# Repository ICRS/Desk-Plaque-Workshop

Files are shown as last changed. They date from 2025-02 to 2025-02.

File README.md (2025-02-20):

# Desk Plaque Workshop

<br>

This is a workshop to make a desk plaque with your name on it. This plaque is lit by LEDs underneath the acrylic nameplate. It is powered by a USB C port and was originally made in the ICRS Robotics lab.

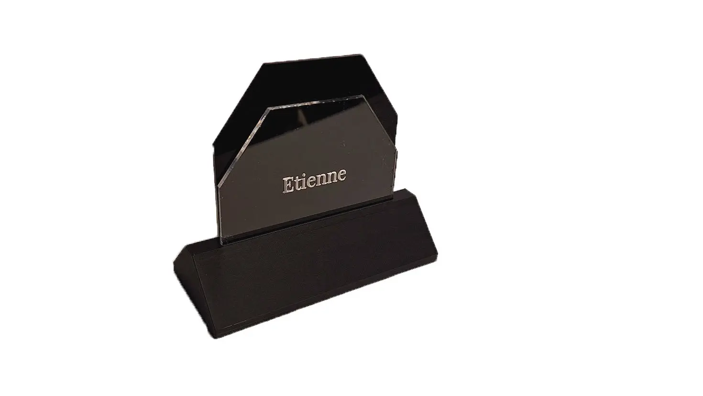
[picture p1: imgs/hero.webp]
hero


<br>
<br>
<br>

| 🔨 Tools | 🪵 Materials |
| ---  | --- |
| Laser Cutter (eg OMTech 60W) | 3mm Black Acrylic |
| 3D Printer (eg Bambu p1p) | 3mm Transparent Acrylic |
| Hot Glue Gun | 3mm Laser Rubber |
| Pliers | PLA Filament |
| Vector Editing Software (eg Inkscape)| USB C Port |
| | Fine Sand |
| | 120 LED/m Warm White LEDs |
| | USB C Cable |

## 📐 Making Parts

#### ⚡ Laser cutting:

1. Follow the instructions in `Name Plate.svg`
2. Remove the protective film from the acrylic
3. Cut out `Name Plate.svg` in the materials specified

#### 🖨️ 3D Printing:

Print all files in `3D files` folder

Use the following settings:

- 0.2mm Layer Height
- 2 Perimeters
- Supports enabled and 0.2mm from parts

Note that the infill percentage for this print doesn't matter.

## 🛠️ Assembly

#### `Electronics:`

1. Cut the LED strip to fit the hole in the base
2. Solder to USB C port

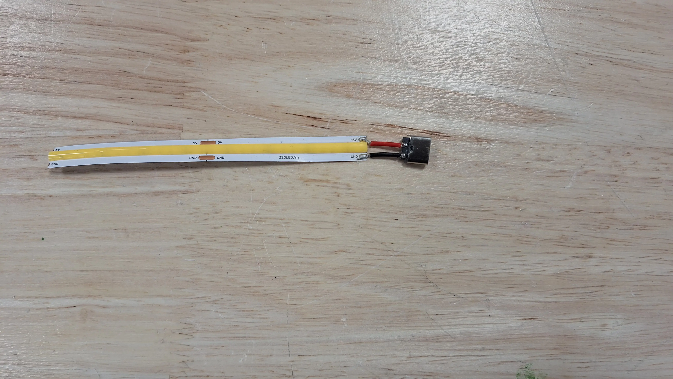
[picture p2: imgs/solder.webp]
LED Strip


#### `Base:`

1. Remove Support from the 3D printed parts
2. Fill the holes of the base with sand
3. Use hot glue to seal the sand holes and add the covers to the base to prevent sand from leaking

---

4. Add the LED strip to the base
5. Cover the LED strip with the 3D printed part and use it to hold the USB C port in place
6. Glue the rubber sheet to the bottom of the base to make it slide less and cover seams

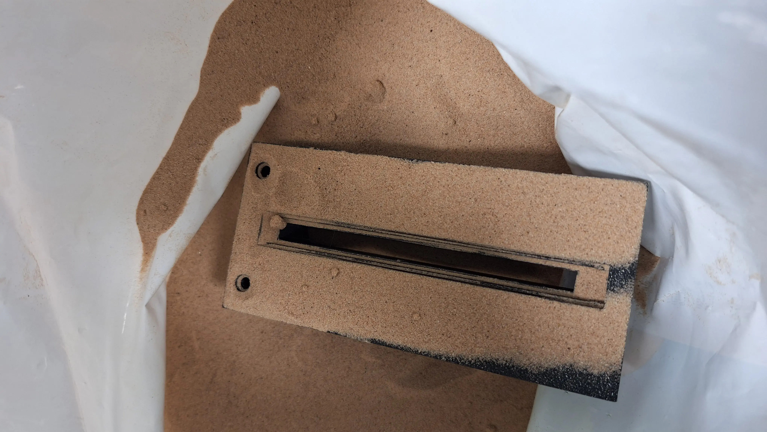
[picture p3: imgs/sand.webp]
sand

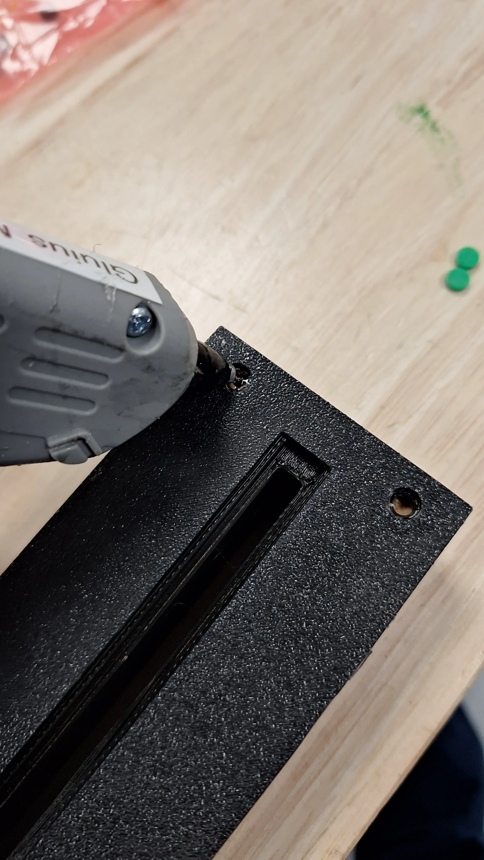
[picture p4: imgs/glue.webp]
glue

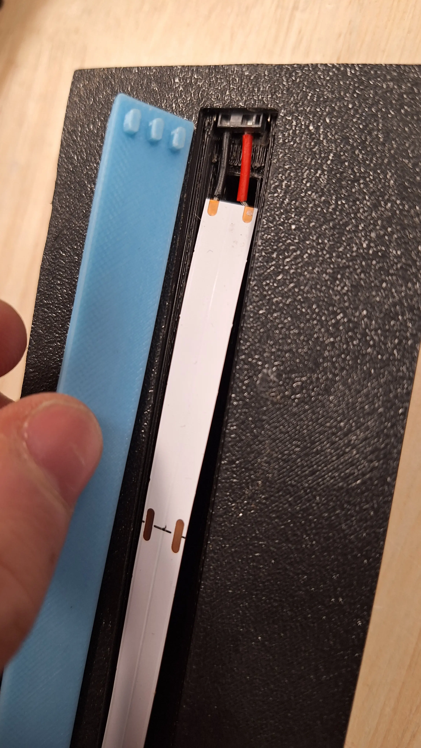
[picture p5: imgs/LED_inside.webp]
led placement


#### `Acrylic:`

1. Remove the protective film from the acrylic
2. Put the transparent acrylic in the slot of the base, with the text facing the inside for maximum contrast
3. Use mallet to gently push the acrlic plate into the slot
4. Then add the black acrylic and mallet it in
5. Plug the USB C port to a power source and enjoy!

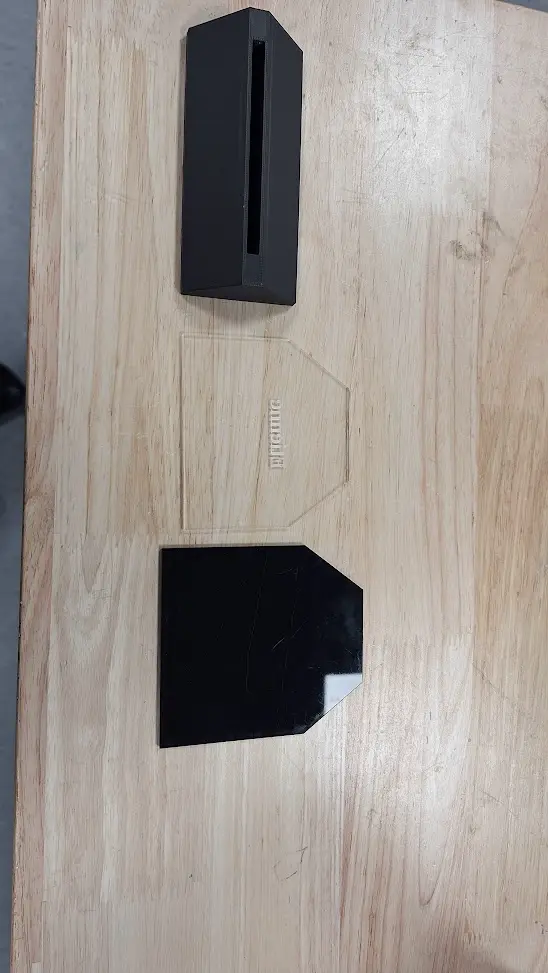
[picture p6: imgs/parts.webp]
parts

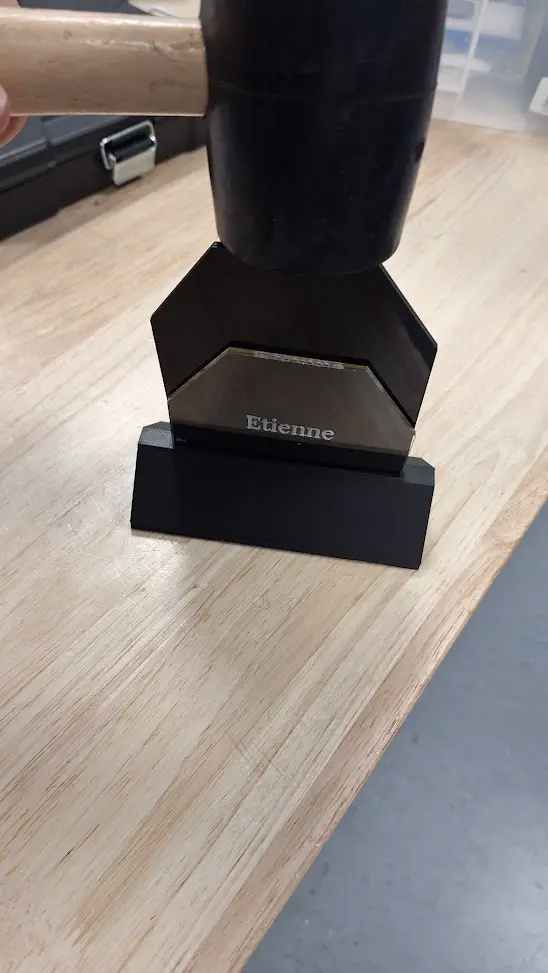
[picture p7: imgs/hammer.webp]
hammer in


### 📞 Contact

Course Designed for [Imperial College Robotics Society](https://linktr.ee/icrobotics)
By
- [Etienne Naude](https://etinaude.dev/contact/)
- [Anna Silver] (anna.silver22@imperial.ac.uk)
- Laura Shaw
- David Cai

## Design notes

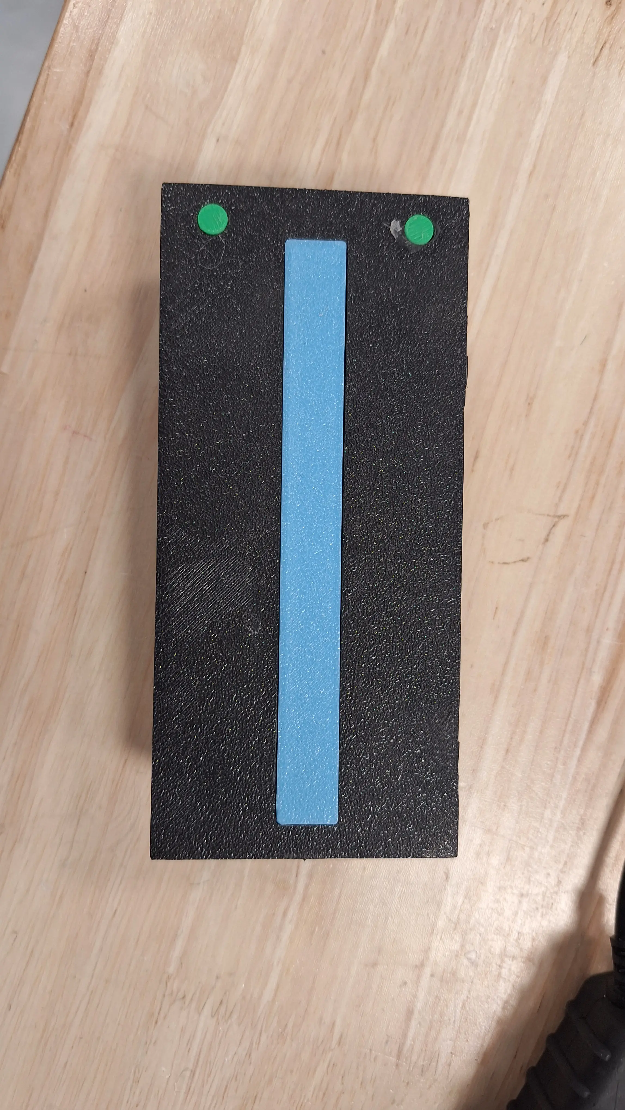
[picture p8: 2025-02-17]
imgs/bottom.webp

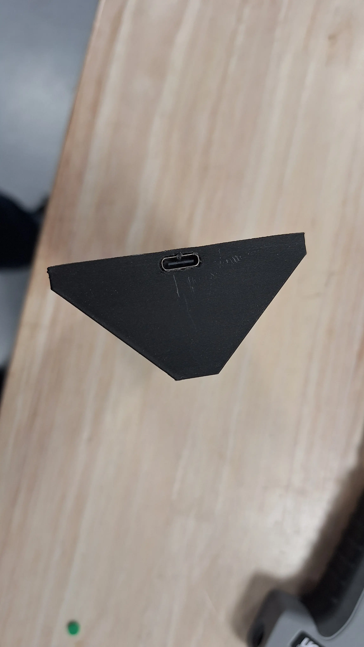
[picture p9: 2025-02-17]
imgs/usb.webp

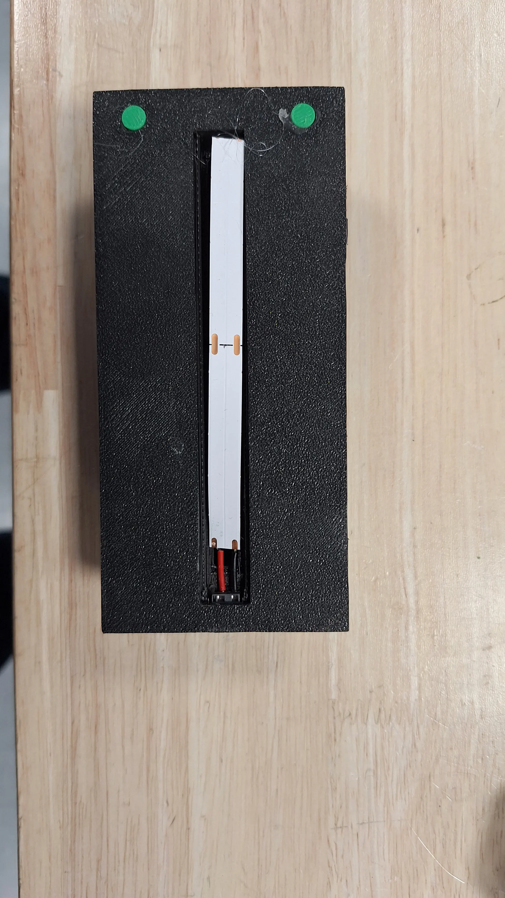
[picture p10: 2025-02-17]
imgs/covers.webp

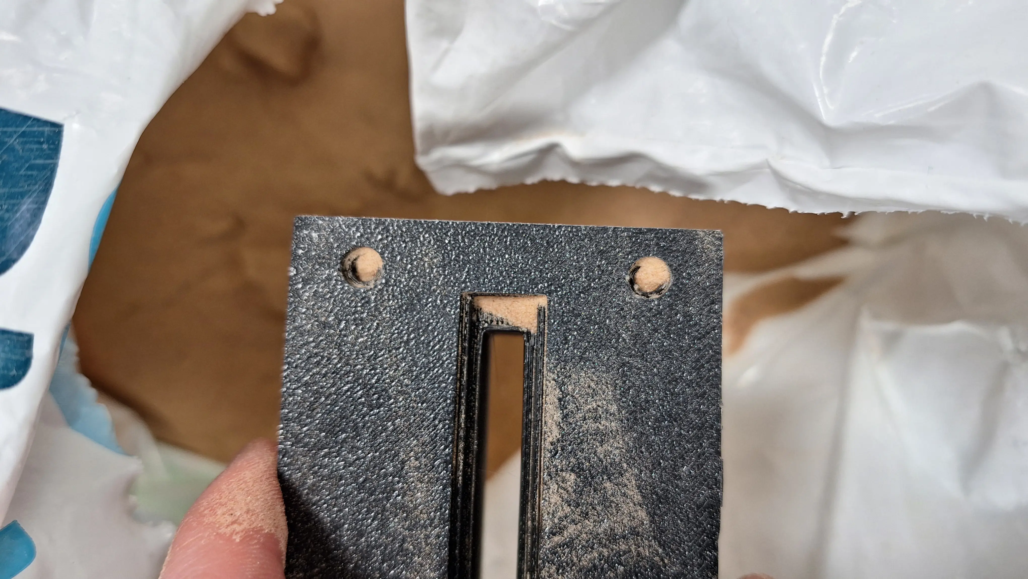
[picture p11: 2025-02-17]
imgs/sand_done.webp

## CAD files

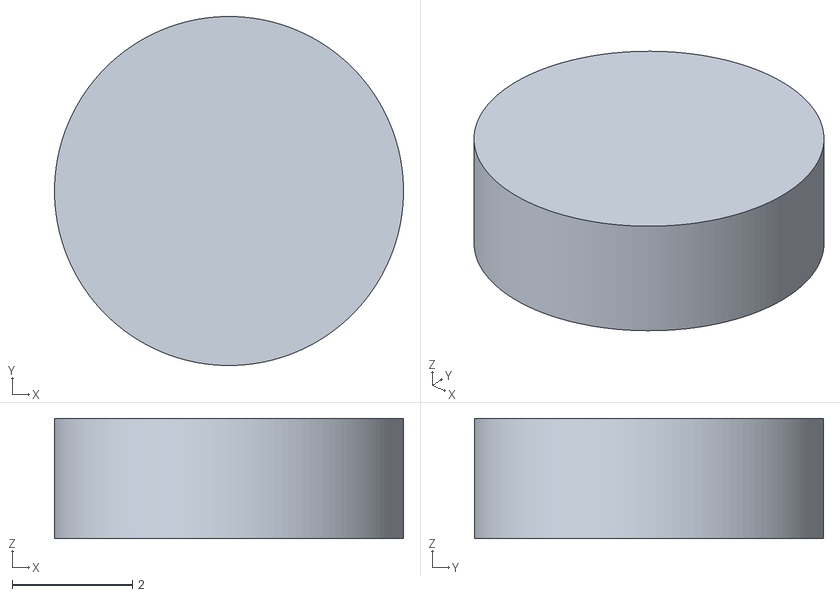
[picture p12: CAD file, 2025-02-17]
3D files/sand cover.stl
5.80 x 5.80 x 2.00

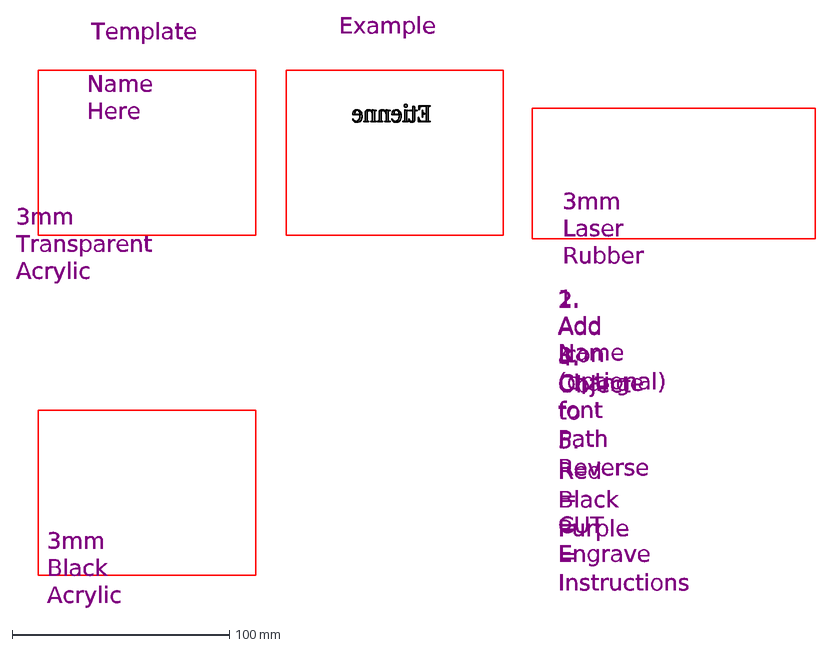
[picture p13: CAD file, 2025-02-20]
Name_Plate_Final.dxf
1. Add Name
2. Add icon (optional)
3. Change font
4. Object to Path
5. Reverse
Red = CUT
Black = Engrave
Purple = Instructions
3mm Black Acrylic
3mm Transparent Acrylic
3mm Laser Rubber
Template
Example
Name Here

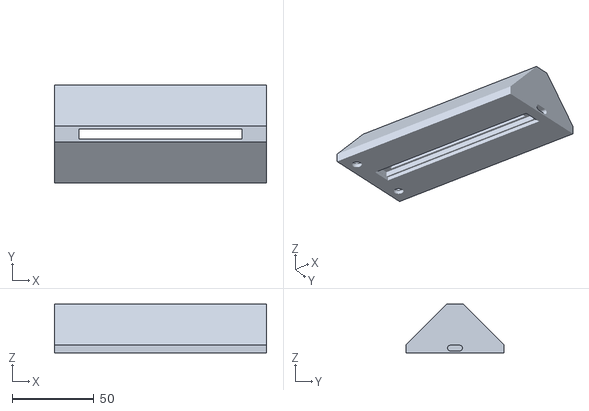
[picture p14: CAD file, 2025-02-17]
3D files/base.stl
130.0 x 60.0 x 30.0

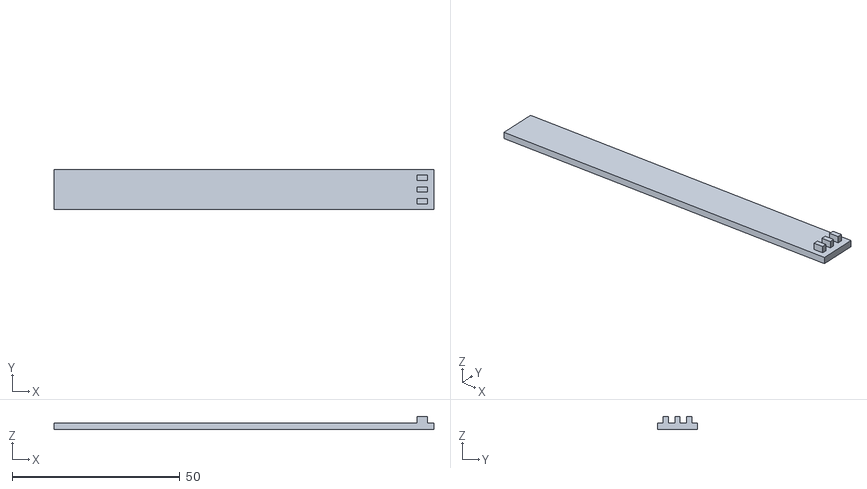
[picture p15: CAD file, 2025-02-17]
3D files/bottom slot.stl
113.1 x 12.0 x 4.00

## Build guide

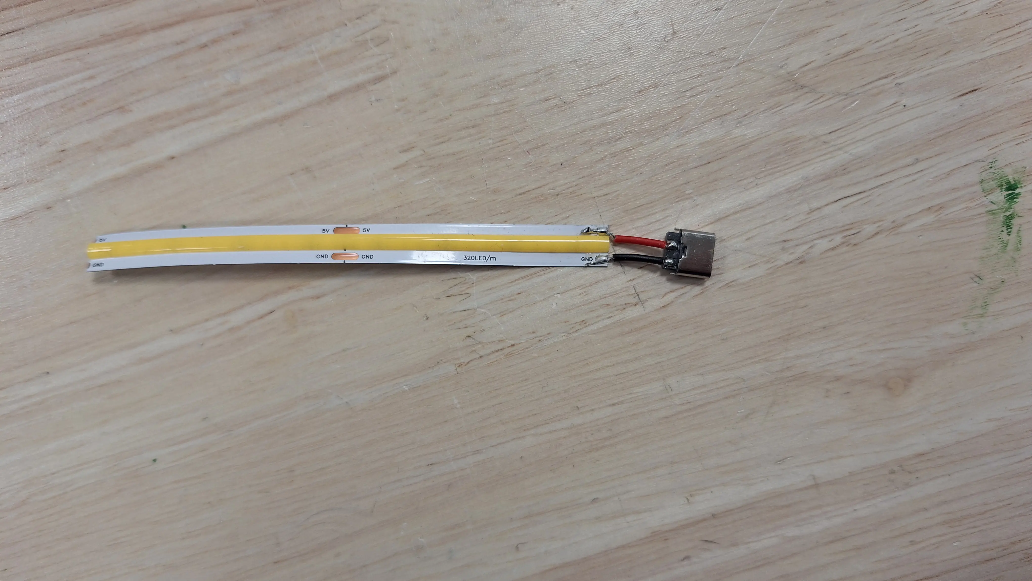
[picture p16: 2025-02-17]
imgs/solder2.webp

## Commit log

2025-02-15 laser file
2025-02-17 3d files
    [base.stl, bottom slot.stl, sand cover.stl]
2025-02-20 Added New File for name_plate
    [Name_Plate_Final.dxf]
